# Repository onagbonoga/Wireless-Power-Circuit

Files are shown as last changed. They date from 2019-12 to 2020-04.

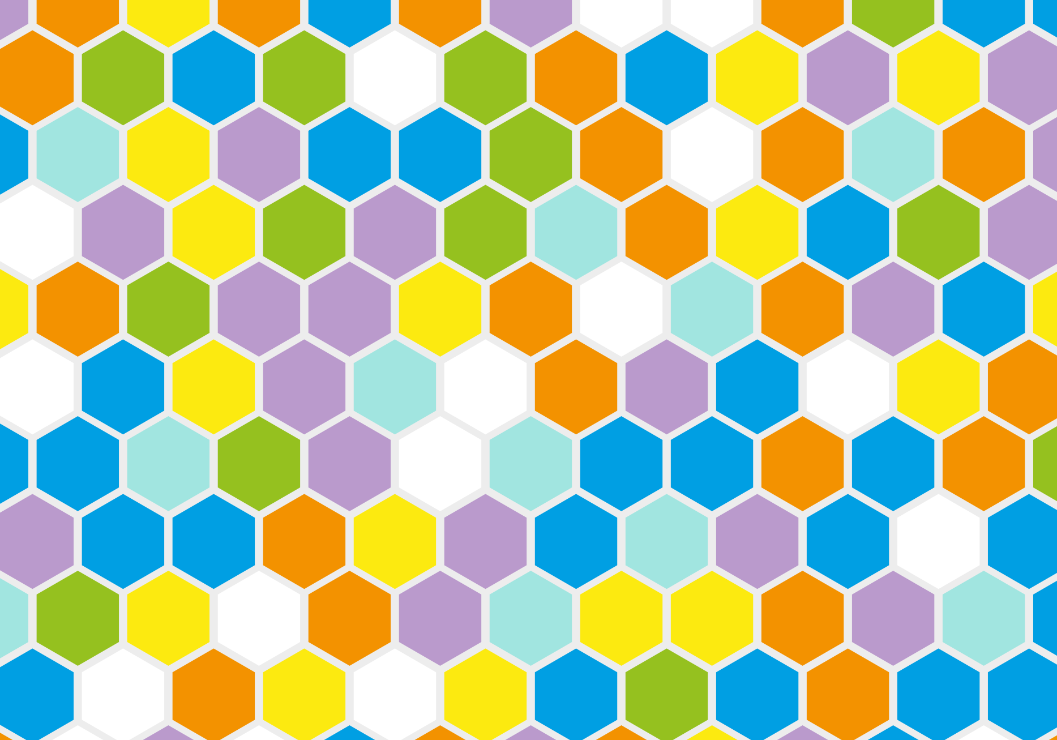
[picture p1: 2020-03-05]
Graphics/Retro Geometric Hexagon.png

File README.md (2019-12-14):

# wireless_power_circuit

Planning on using: 28 AWG magnet wire.
http://www.tesla-institute.com/!app/sim/fscic.php

Coil ID: 30 mm
Number of Turns: 50
Wire diameter used: 0.32 mm
Spacing between turns: 0.05 mm (very rough guess)

Inductance (L): 145.61 uH (Theoretical)
Coil OD: 67 mm
Wire length: 7.618 m

Inductance (L): 417.5 uH (Practical - E05 measurements)

Capacitor parameters: 500 mm length x width of foil tape (~50mm).
Capacitor dielectric: wax paper (unknown permitivity).

Measured capacitance: ~9.3 nF

Resonant frequency (1/(2*pi*sqrt(L*C))): ~136.77 kHz (Based on theoretical L)
Resonant frequency (1/(2*pi*sqrt(L*C))): ~80.77 kHz (Based on measured L - E05)
Resonant frequency (measured) = ??

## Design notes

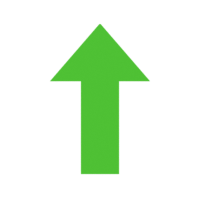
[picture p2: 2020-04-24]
Graphics/arrow.png

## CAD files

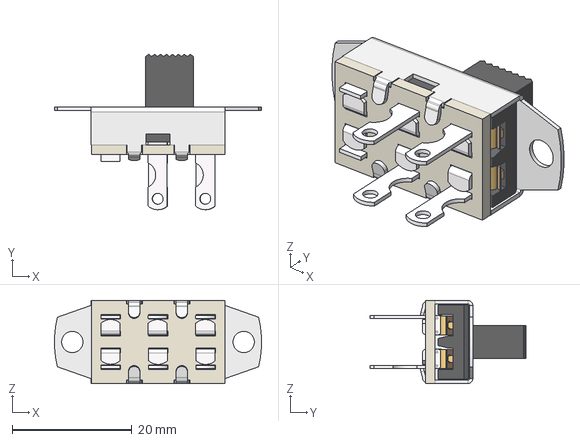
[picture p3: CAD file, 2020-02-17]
Electrical/_lib/3D/GF-325-0000_3D MODEL.stp
34.5 x 25.9 x 13.8 mm

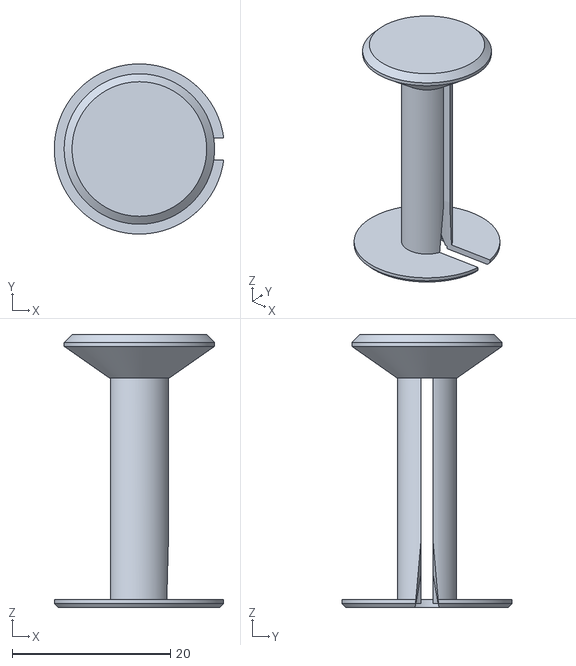
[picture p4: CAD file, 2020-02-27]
Mechanical/CAM/Secondary/STL/Spindle.stl
21.4 x 21.5 x 34.5

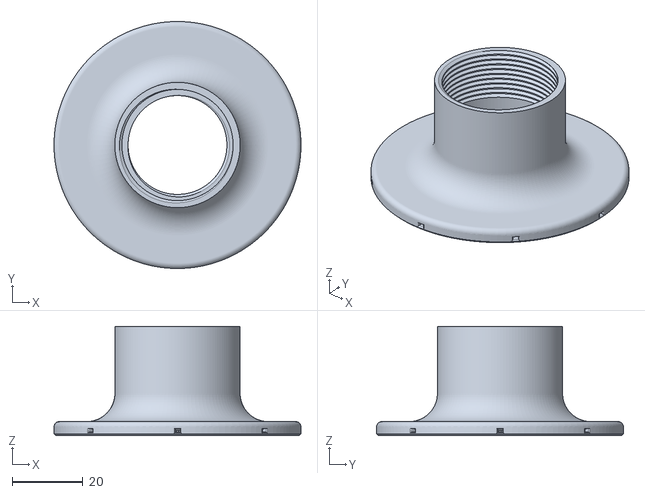
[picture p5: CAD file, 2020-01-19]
Mechanical/CAM/STL/Top_Plate.stl
70.0 x 70.0 x 31.0

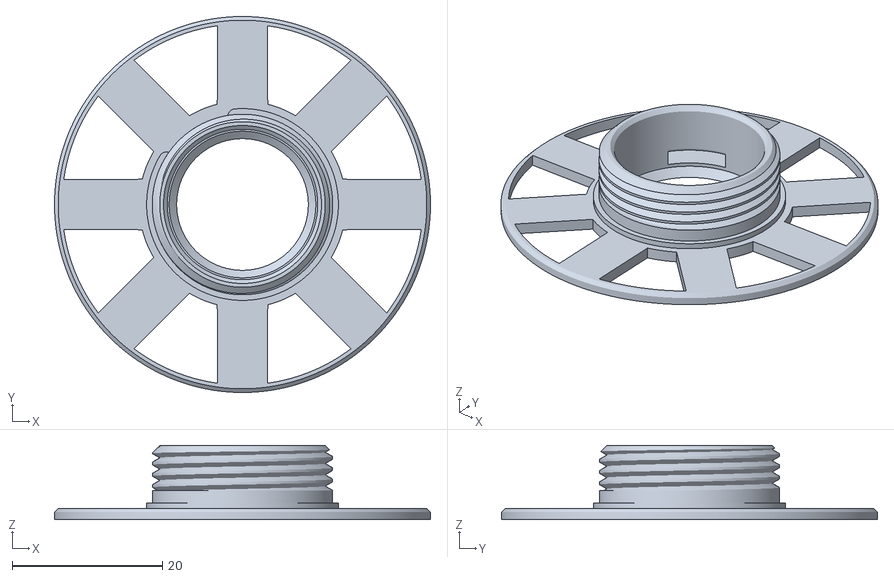
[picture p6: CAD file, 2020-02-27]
Mechanical/CAM/Secondary/STL/Base_Plate.stl
50.0 x 50.0 x 9.90

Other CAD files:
Mechanical/CAD/Primary/PCB.iges
Graphics/capacitor.blend
Graphics/coil.blend
Graphics/videoedit.blend

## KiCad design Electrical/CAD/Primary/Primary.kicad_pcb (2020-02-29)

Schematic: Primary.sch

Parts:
BT1: 2x_Battery_Cell; Keystone_Dual_AA_Holder
C1, C2: 10nF; C_Disc_D6.0mm_W2.5mm_P5.00mm
C3: 470pF; C_Disc_D6.0mm_W2.5mm_P5.00mm
C4: C; C_Disc_D6.0mm_W2.5mm_P5.00mm
L1: L; CoilSpiral_25_Bezier
Q1: 2N3904; TO-92_Inline
Q2: 2N3906; TO-92_Inline
R1: 33k; R_Axial_DIN0207_L6.3mm_D2.5mm_P7.62mm_Horizontal
R2: 1M; R_Axial_DIN0207_L6.3mm_D2.5mm_P7.62mm_Horizontal
R3: 2.2k; R_Axial_DIN0207_L6.3mm_D2.5mm_P7.62mm_Horizontal
R4: 5.1; R_Axial_DIN0207_L6.3mm_D2.5mm_P7.62mm_Horizontal
SW1: SW_DPST; GF-325
U1: LMC555xN; DIP-8_W7.62mm
U2: MCP6282

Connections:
+1V5: C4.2, L1.2, SW1.2, U2.3
+3V0: Q1.3 (C), R2.1, SW1.4, U1.4, U1.8, U2.8
GND: BT1.3 (-), C1.2, C2.2, Q2.3 (C), U1.1, U2.4
unnamed: BT1.1 (+), SW1.3
unnamed: BT1.2 (+), BT1.4 (-), SW1.1
unnamed: C1.1, U1.5
unnamed: C2.1, R1.2, R2.2, U1.2, U1.6
unnamed: C3.1, U2.1, U2.5
unnamed: C3.2, R3.1, U2.2
unnamed: C4.1, L1.1, R4.2
unnamed: Q1.1 (E), Q2.1 (E), R4.1, U2.6
unnamed: Q1.2 (B), Q2.2 (B), U2.7
unnamed: R1.1, R3.2, U1.3

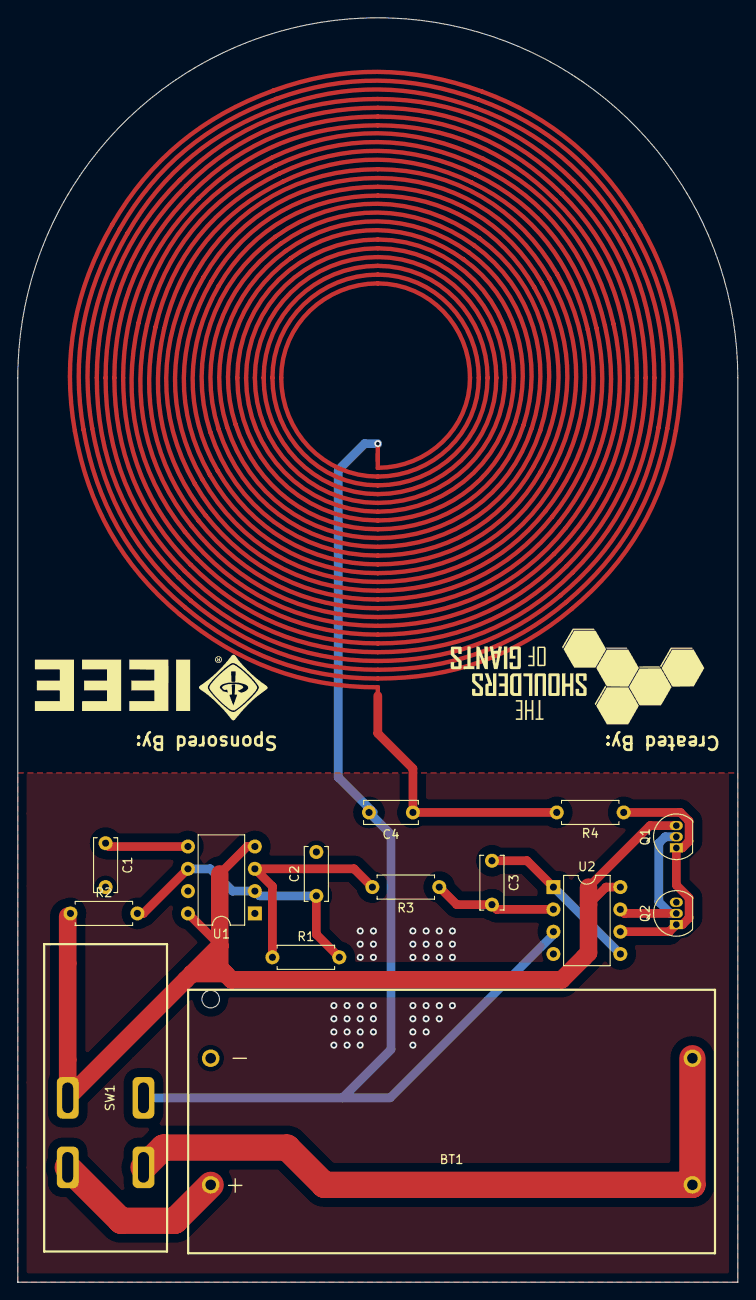
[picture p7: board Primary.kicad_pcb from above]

Board: 2 copper layers, 82.0 x 144.0 mm, 15 parts (0 on the bottom side), 13 nets.

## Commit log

2019-11-30 Added CAM files.
    [Base_Plate.stl, Top_Plate.stl]
2019-12-14 Pre-episode 5 updates.
    [Base_Plate.stl, Top_Plate.stl]
2019-12-14 Rounded spacing nubs on base plate.
2019-12-16 Modifications to improve wire spooling.
    [Base_Plate.stl, Top_Plate.stl]
2020-01-19 End of episode 6.
    [Primary.kicad_pcb, Primary.sch]
2020-01-26 End of Episode 7.
    [Primary.kicad_pcb]
2020-02-16 Mid episode 10 commit.
    [Primary.kicad_pcb, Primary.sch]
2020-02-17 End of episode 10 commit.
    [Primary.kicad_pcb]
2020-02-17 Merging spiral-component changes into master.
    [GF-325-0000_3D MODEL.stp, Primary.kicad_pcb]
2020-02-18 Generated Gerber files.
    [Primary.kicad_pcb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]
2020-02-23 Modified housing and added 3D models to PCB.
    [Base_Plate.stl, Spindle.stl]
2020-02-27 Updated GCode_Files
    [Base_Plate.stl, Spindle.stl]
2020-02-29 Minor CAD / CAM updates.
    [Primary-B_Cu.gbr, Primary-B_Mask.gbr, Primary-Edge_Cuts.gbr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]
2020-02-29 Modified footprints for caps and battery on primary PCB.
    [Primary.kicad_pcb, Primary.sch]
2020-02-29 PCB: fix route to new capacitor footprints
    [Primary.kicad_pcb]
2020-02-29 PCB: change pads for switch to slots
    [Primary.kicad_pcb]
2020-02-29 PCB: fix remaining tracks that were too close to pins, make slots for switch .25mm longer
    [Primary.kicad_pcb]
2020-02-29 End of Episode 12.
    [PCB.iges]
2020-04-24 Added video and relevant files
    [capacitor.blend, coil.blend, videoedit.blend]
2020-04-24 updated video
    [videoedit.blend]
